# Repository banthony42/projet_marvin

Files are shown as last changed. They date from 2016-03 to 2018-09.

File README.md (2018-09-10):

# Projet Electronics 42
Le projet électronique consiste à fabriquer un prototype du projet de son choix : circuit et firmware. On n'utilise pas de raspberry pi ou d'arduino, on les fabrique ! Pour suivre ce projet vous aurez besoin de savoir lire l'anglais et d'avoir un niveau correct en C (opérations binaires notamment). Préparez-vous à suivre l'un des projets les plus durs du cursus et à sortir complètement de votre zone de confort. Vous serez en mode piscine au carré, et c'est voulu. Comptez une à deux journées par semaine minimum pendant 6 mois pour aller au bout du projet.

# projet_marvin
Le projet Marvin a pour ambition de construire une réplique animatronique du robot dépressif Marvin, personnage du Guide du Voyageur Galactique de Douglas Adams.

Etant donnée l'ampleur de la tâche, et afin de nous concentrer sur les aspects électroniques plutôt que sur la conception d'assemblages mécaniques, nous avons choisi de nous concentrer exclusivement sur la tête de cet humanoïde, à priori à une échelle de 1/3.

La tête de notre robot pourra se mouvoir selon deux axes (tangage et lacet) afin de suivre du “regard” son interlocuteur, comportera des éléments lumineux, des capteurs, ainsi que la capacité de jouer des extraits sonores via un haut-parleur.

Notre conception électronique assurera la régulation de la tension, l'asservissement des actionneurs ainsi que le traitement des signaux issus des capteurs.

En option, nous pourrons augmenter les capacités sensorielles de Marvin en adjoignant au PIC32 un ordinateur type Raspberry Pi ainsi que des capteurs avancés : deux micros pour la localisation d’une source de bruit, et une caméra pour un head tracking plus fin.

**Equipe du projet:
Lefr0g,
Aodren92,
banthony42,
Theo Beaumanoir**

### Aperçu des réalisations
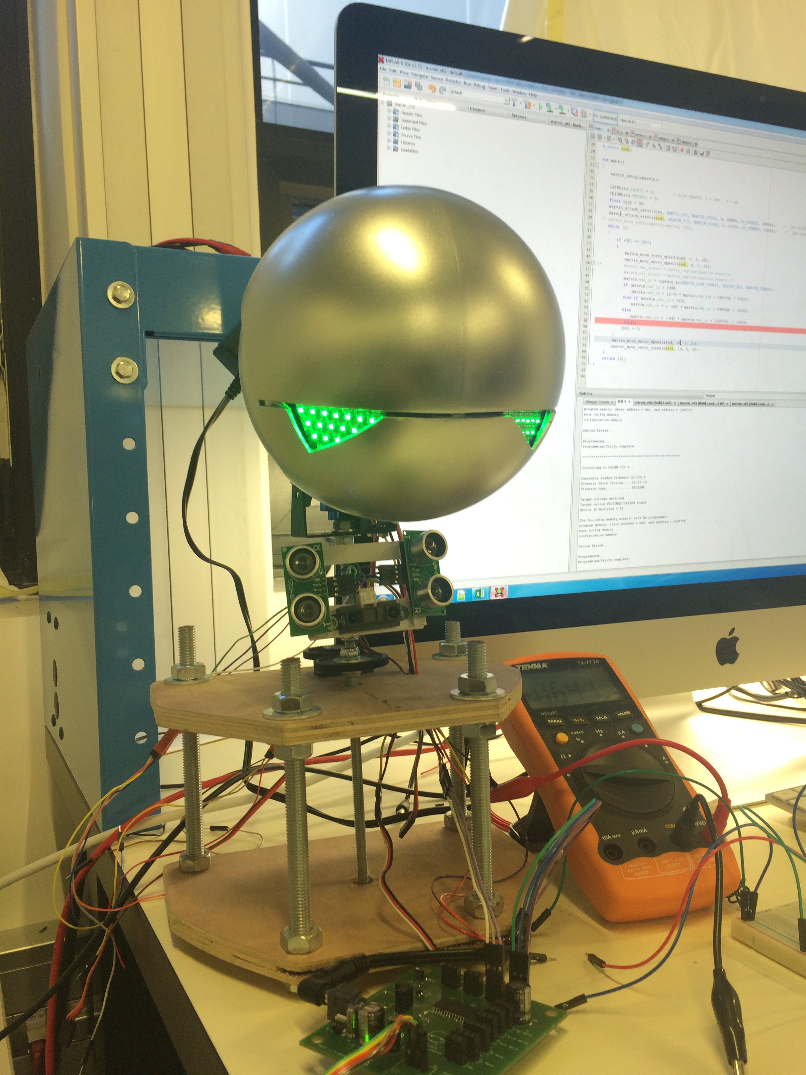
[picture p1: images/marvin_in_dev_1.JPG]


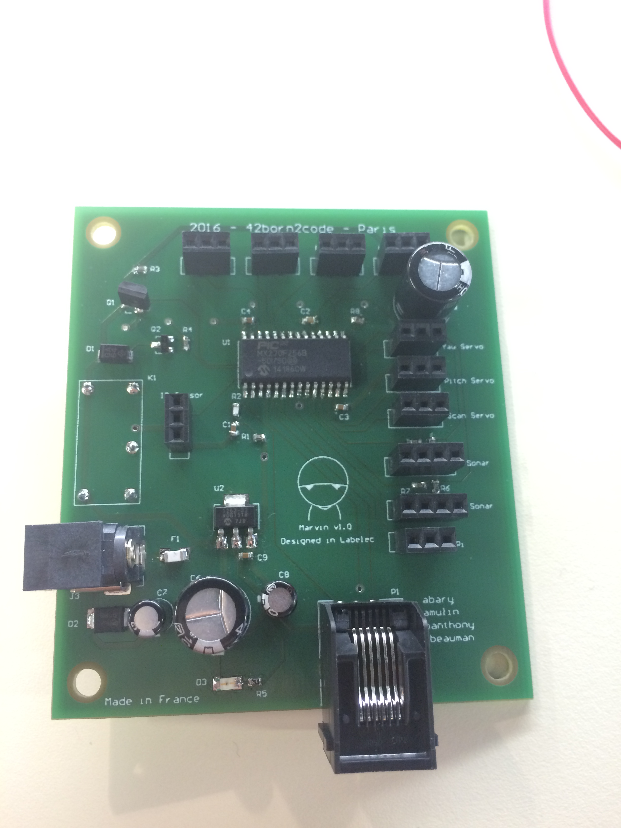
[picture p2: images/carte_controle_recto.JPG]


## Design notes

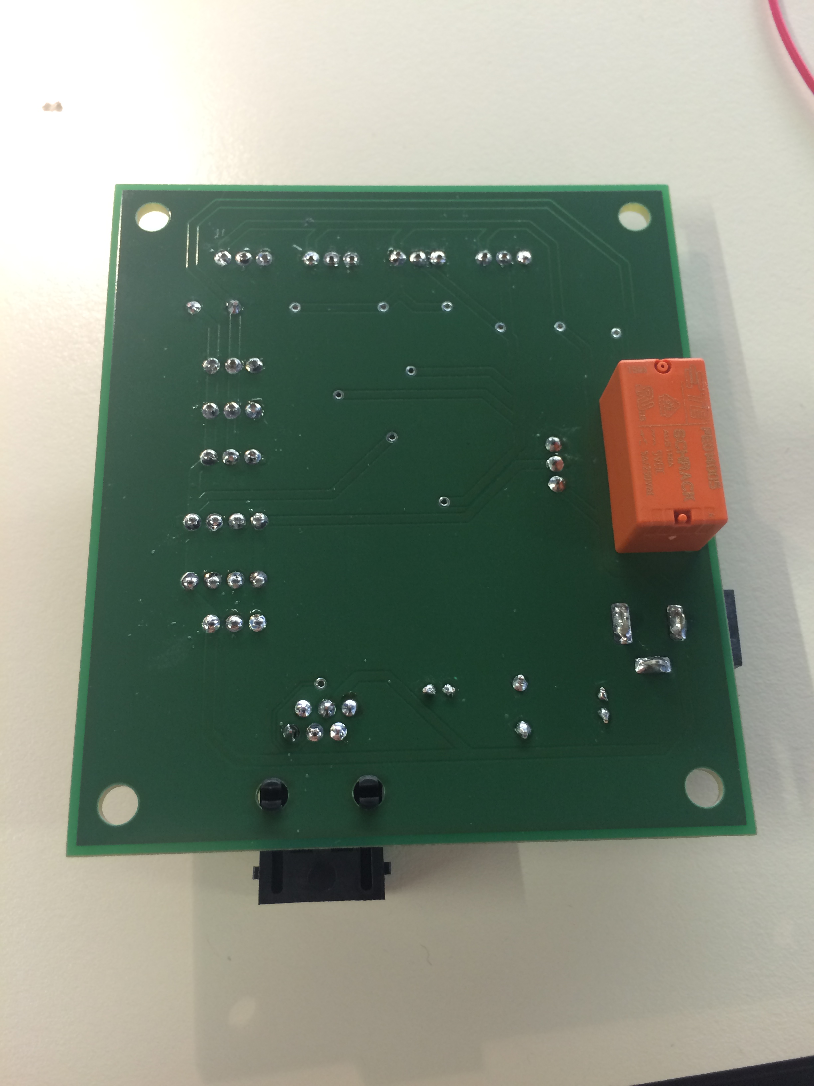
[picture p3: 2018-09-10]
images/carte_controle_verso.JPG

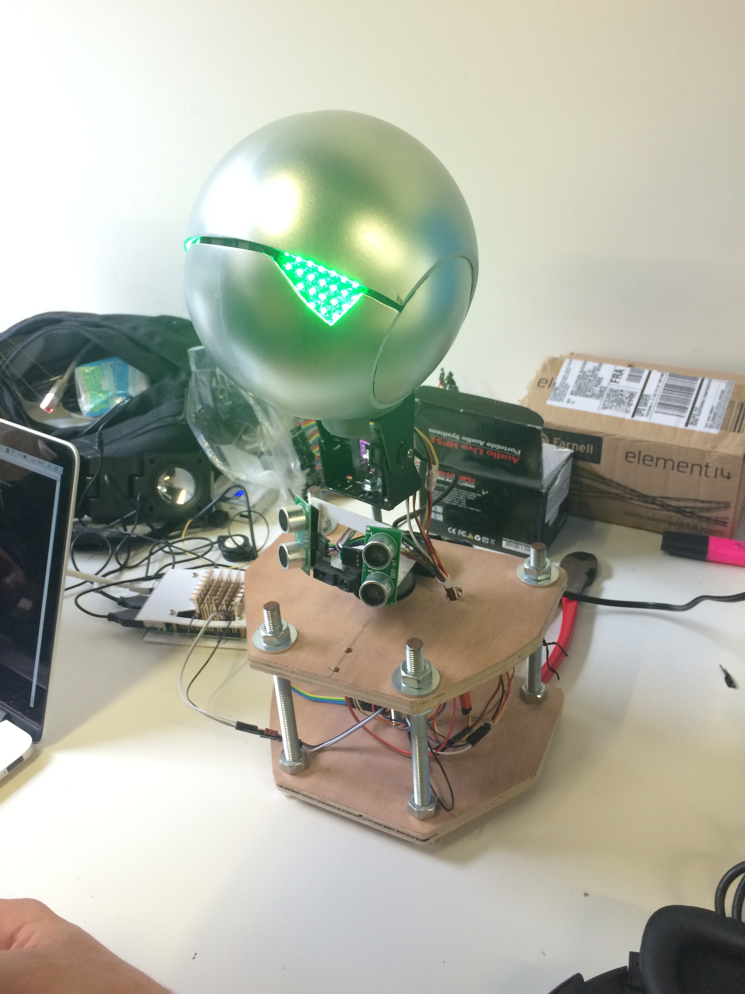
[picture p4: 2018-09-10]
images/marvin_in_dev_2.JPG

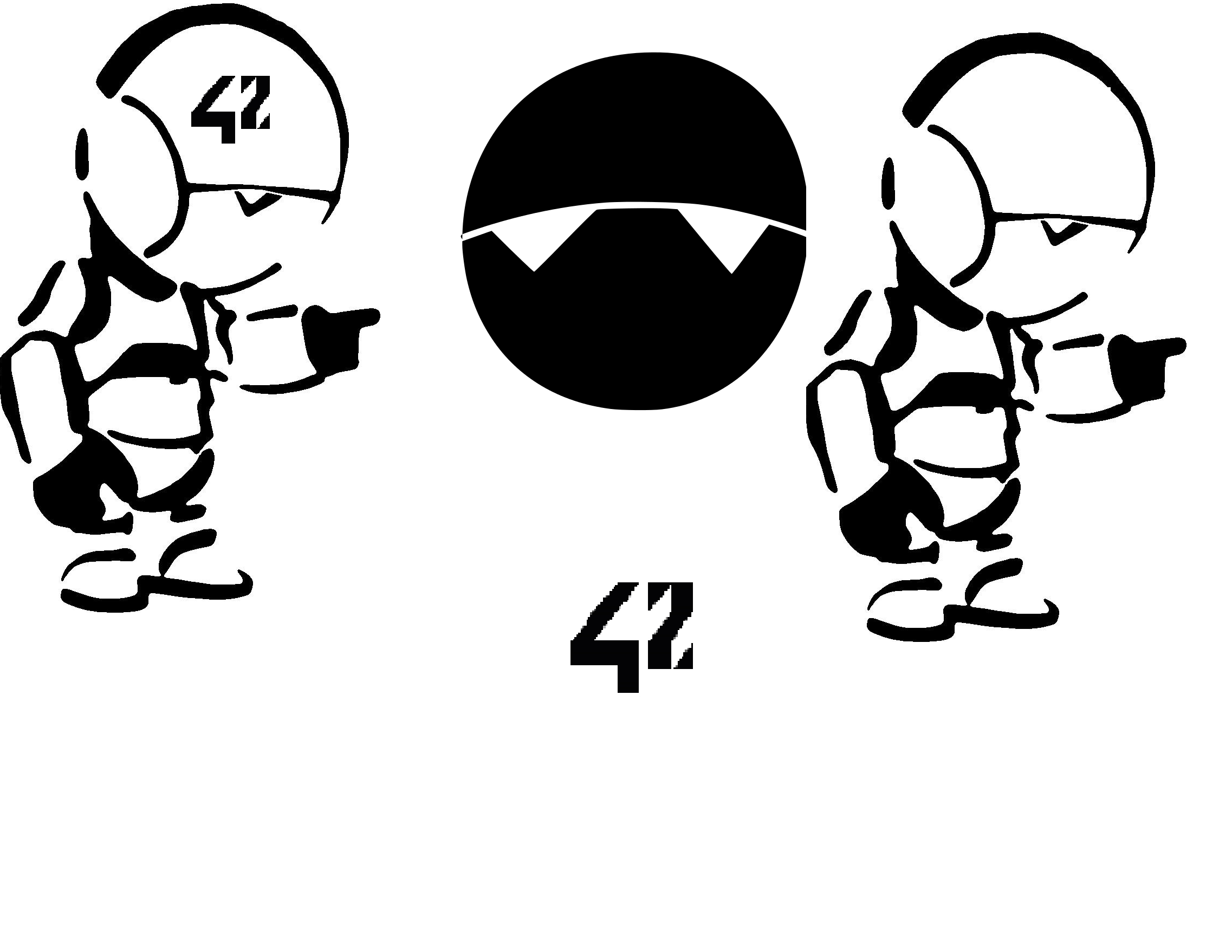
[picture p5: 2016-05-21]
POC/Altium/marvin_front.png

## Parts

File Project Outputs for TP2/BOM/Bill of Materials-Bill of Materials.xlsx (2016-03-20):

Comment | Description | DesignItemId | Quantity | Value | Fabricant | Footprint | Fournisseur | RefFabricant | RefFournisseur | Designator
100nF | Capacitor | Cap | 7 | 100pF |  | CAPC1608N |  |  |  | C1, C2, C3, C4, C5, C6, C15
20pF | Capacitor | Cap | 2 | 100pF |  | CAPC1608N |  |  |  | C7, C8
10uF | Capacitor | Cap | 4 | 100pF | [NoValue], TDK, TDK, TDK | CAPC2012N | [NoValue], Farnell, Farnell, Farnell | [NoValue], C2012X5R0J106M/1.25, C2012X5R0J106M/1.25, C2012X5R0J106M/1.25 | [NoValue], 2309029, 2309029, 2309029 | C9, C11, C12, C13
1uF | Capacitor | Cap | 2 | 100pF |  | CAPC1608N |  |  |  | C10, C14
GF1A | Default Diode | Diode | 2 |  | VISHAY | SMA/DO-214AC_21 | Farnell | GF1A-E3/67A | 9549560 | D2, D3
Green LED | Typical RED, GREEN, YELLOW, AMBER GaAs LED | LED2 | 5 |  | KINGBRIGHT | LED 0805 | Farnell | KPT-2012SGC | 2099239 | D4, LED3_LED0, LED3_LED1, LED3_LED2, LED3_LED3
600r | Inductor | Inductor | 1 | 600r | Wurth | INDC1608AN | Farnell | 742792651 | 1635706 | FB1
Program / Debug |  | Program / Debug | 1 |  | Molex | RJ12_90 | Farnell | 53398-0671 | 1125368 | J1
12V Main | Header, 2-Pin | Header 2 | 1 |  | PHOENIX CONTACT | PHOENIX_1985195 | Farnell | PTSA1.5/2-3.5-Z | 1792679 | P1
12V Battery | Header, 2-Pin | Header 2 | 1 |  | PHOENIX CONTACT | PHOENIX_1985195 | Farnell | PTSA1.5/2-3.5-Z | 1792769 | P2
10k | Potentiometer | RPot | 1 | 10K | Bourns | PDB181-K415K-102A2 | Farnell | 'PDB181-K415K-102A2 | '1823540 | R1
330r | Resistor | Res1 | 4 | 1K |  | RESC1608N |  |  |  | R2_LED0, R2_LED1, R2_LED2, R2_LED3
4.7k | Resistor | Res1 | 1 | 1K |  | RESC1608N |  |  |  | R3
470r | Resistor | Res1 | 1 | 1K |  | RESC1608N |  |  |  | R4
PIC32MX764F128H-I/PT |  | PIC32MX764F128H-I/PT | 1 |  | Microchip | QFP50P1200X1200X120-64 | Farnell | PIC32MX764F128H-I/PT | 1971889 | U1
AP1117 |  | AP1117 | 1 |  | DIODES INC | TD03B_N | Farnell | AP1117D33G-13 | 1825285 | U2
8MHz | Crystal Oscillator | XTAL | 1 |  | FOX ELECTRONICS | HC49/4H SMX CRYSTAL | Farnell | FOXSDLF/080-20 | 2063972 | Y1

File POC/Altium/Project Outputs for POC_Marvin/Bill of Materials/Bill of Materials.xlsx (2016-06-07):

Comment | Description | Footprint | LogicalDesignator | Quantity | fabricant | reffabricant | fournisseur | reffournisseur
470uF | Capacitor | CONDO_D_10mm | C5, C6 | 2 | Panasonic | ECA-1EHG471, [NoValue] | Farnell | 9692843
10uF | Capacitor | CONDO_D_5MM | C7, C8 | 2 | Panasonic | ECA-1JHG100 | Farnell | 1848557
GF1A | Default Diode | SMA/DO-214AC_21 | D1 | 1 | VISHAY | GF1A-E3/67A | Farnell | 9549560
Zener 1SMB5918BT3G | Zener Diode | DIODE ZENER | D2 | 1 | ON SEMICONDUCTORS | 1SMB5918BT3G | Farnell | 1431161
150120VS75000 | Green LED | 3216 / 1206 | D3 | 31 | WURTH ELEKTRONIK | 150120VS75000 | Farnell | 2322088
1206SFF500F/32-2 | Fuse | 3216 / 1206 | F1 | 5 | TE CONNECTIVITY / RAYCHEM | 1206SFF500F/32-2 | Farnell | 1843811
IR_Connector | Female Embase 3 contacts | IR SENSOR CONNECTOR | J1 | 1 | TE CONNECTIVITY / AMP | 5-534237-1 | Farnell | 1845931
Potard_Connector | Female Embase 3 contacts | POTARD CONNECTOR | J2 | 2 | TE CONNECTIVITY / AMP | 5-534237-1 | Farnell | 1845931
PWR2.5 RAPC712BK | Jack Connector | RAPC712BK | J3 | 1 | SWITCHCRAFT | RAPC712BK | Farnell | 1617204
RPi_Connector | Female Embase 3 contacts | RPI CONNECTOR | J4 | 1 | TE CONNECTIVITY / AMP | 5-534237-1 | Farnell | 1845931
Servo_Connector | Female Embase 3 contacts | SERVO CONNECTOR | J5 | 3 | TE CONNECTIVITY / AMP | 5-534237-1 | Farnell | 1845931
Sonar_Connector | Female Embase 4 contacts | SONAR CONNECTOR | J6 | 2 | TE CONNECTIVITY / AMP | 5-534237-2 | Farnell | 1845959
Leds_Connector | Female Embase 3 contacts | LEDS CONNECTOR | J7 | 2 | TE CONNECTIVITY / AMP | 5-534237-1 | Farnell | 1845931
Relay PE014005 | Relay | PE014005 | K1 | 1 | TE CONNECTIVITY / SCHRACK | PE014005 | Farnell | 1175088
RJ11 Debug | RJ11 Connector | RJ11 | P1 | 1 | MOLEX | 95009-7661 | Farnell | 2076092
MOSFET-N 2N7002K | N-Channel MOSFET | SOT23 | Q2 | 1 | FAIRCHILD SEMICONDUCTOR | 2N7002K | Farnell | 2453382
PIC32MX270F256B | PIC32MX270F256B | SOIC28 | U1 | 1 | Microchip | PIC32MX270F256B-50I/SO | Farnell | 2419680
Regul LD1117S33TR | Voltage Regulator | SOT-223 | U2 | 1 | ST MICRO | LD1117S33TR | Farnell | 1202826

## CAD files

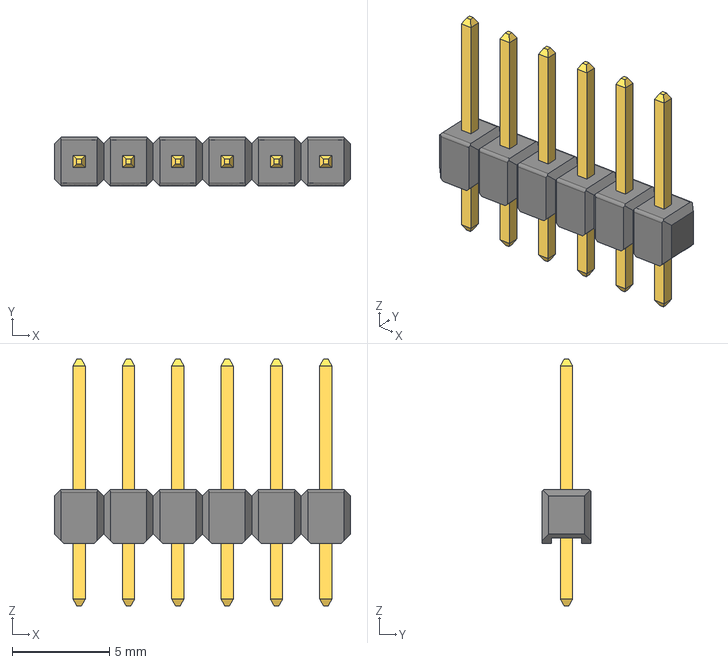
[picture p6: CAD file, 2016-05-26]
POC/Altium/Pin Header 1x6 TH Pitch 2.54mm.stp
15.2 x 2.54 x 12.7 mm

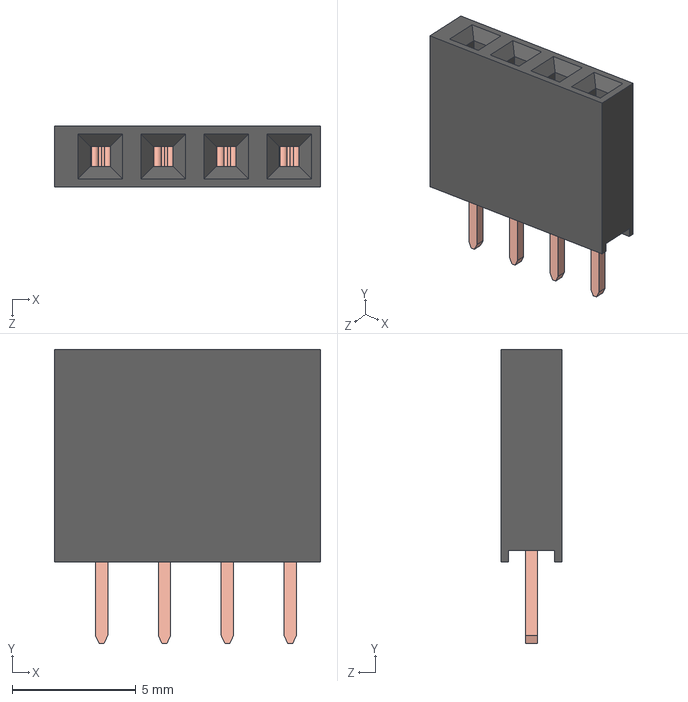
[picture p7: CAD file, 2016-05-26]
POC/Altium/SIMON_4pinheader-female-STEP.STEP
10.8 x 11.9 x 2.48 mm

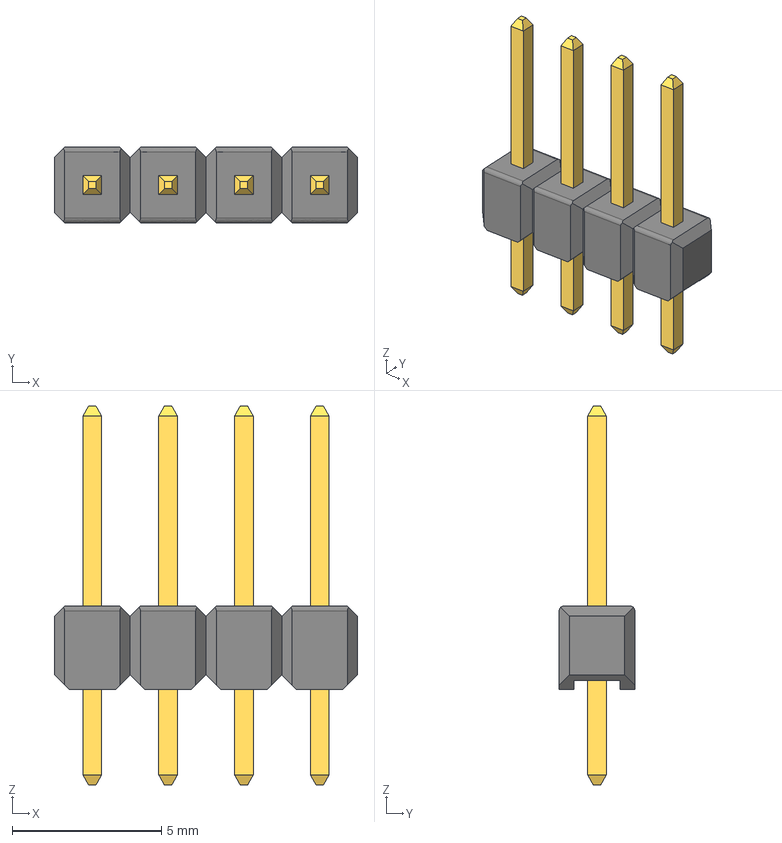
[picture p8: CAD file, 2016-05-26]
POC/Altium/Pin Header 1x4 TH Pitch 2.54mm.stp
10.2 x 2.54 x 12.7 mm

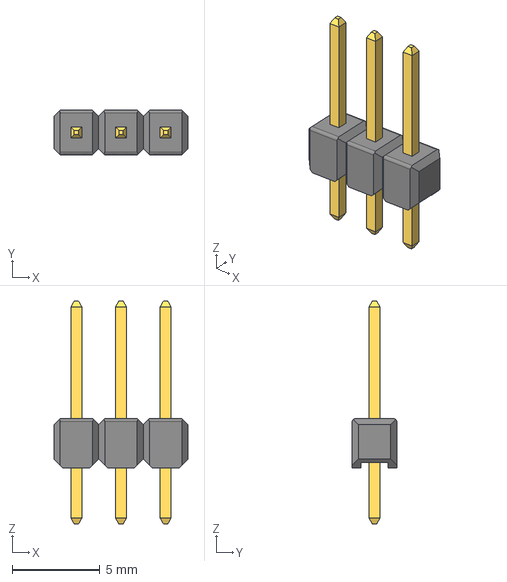
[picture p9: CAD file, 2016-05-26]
POC/Altium/Pin Header 1x3 TH Pitch 2.54mm.stp
7.62 x 2.54 x 12.7 mm

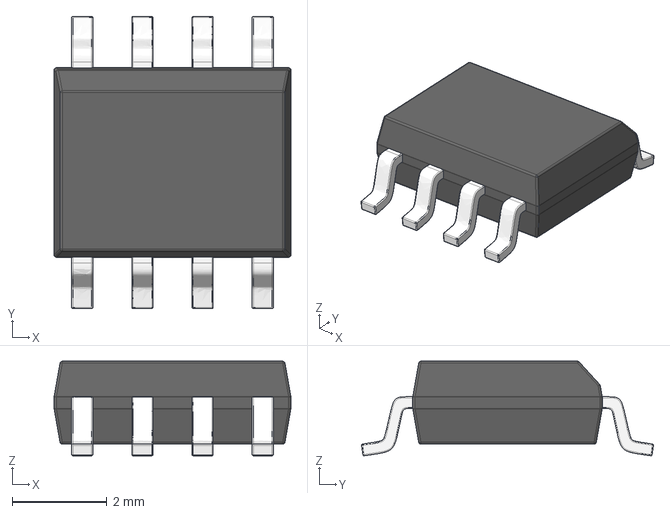
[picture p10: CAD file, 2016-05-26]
POC/Altium/SOIC08 narrow.stp
5.00 x 6.16 x 2.00 mm

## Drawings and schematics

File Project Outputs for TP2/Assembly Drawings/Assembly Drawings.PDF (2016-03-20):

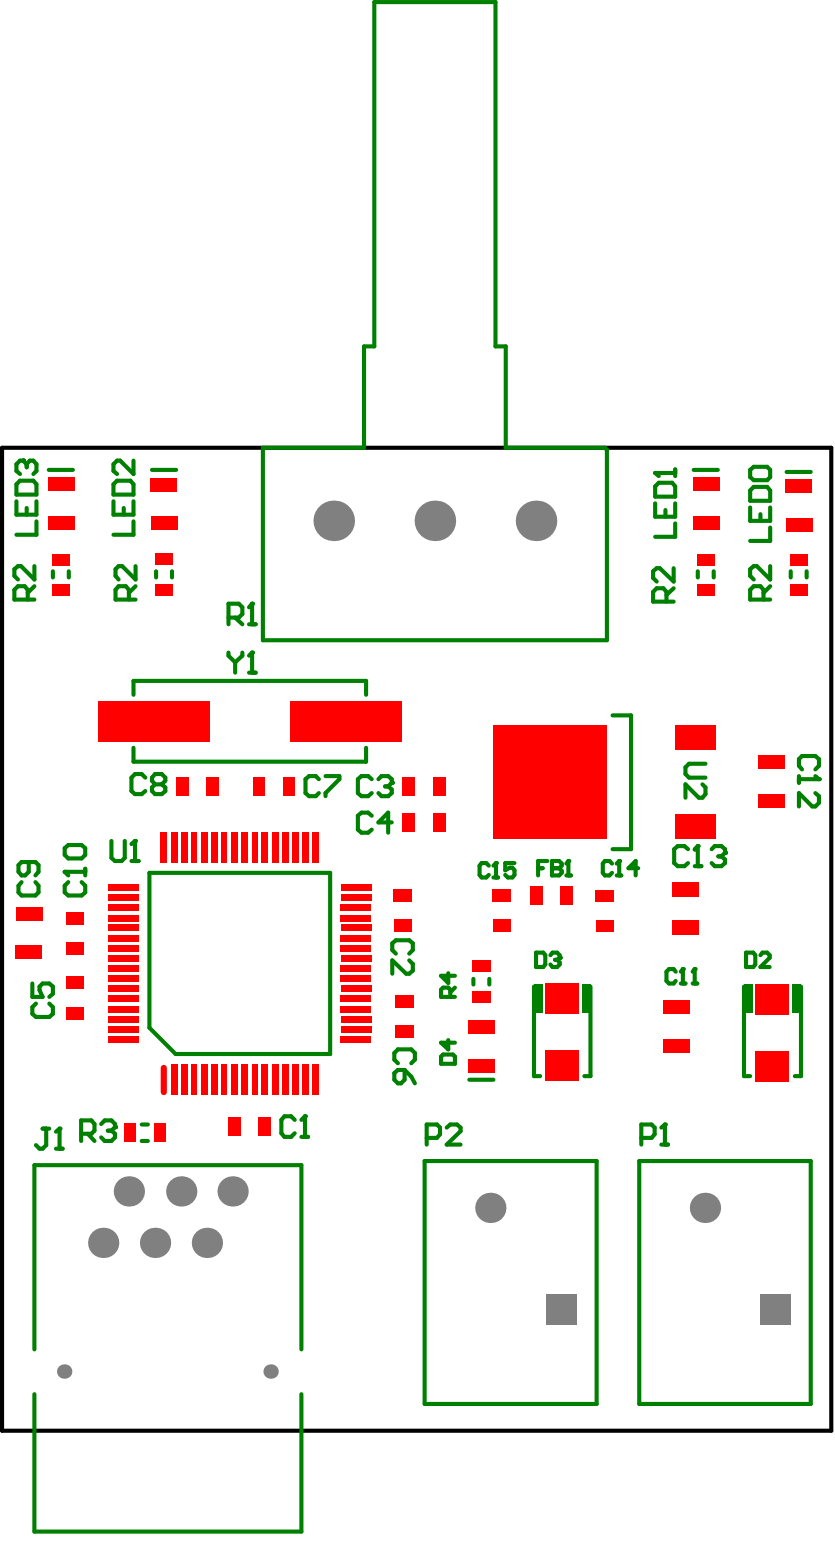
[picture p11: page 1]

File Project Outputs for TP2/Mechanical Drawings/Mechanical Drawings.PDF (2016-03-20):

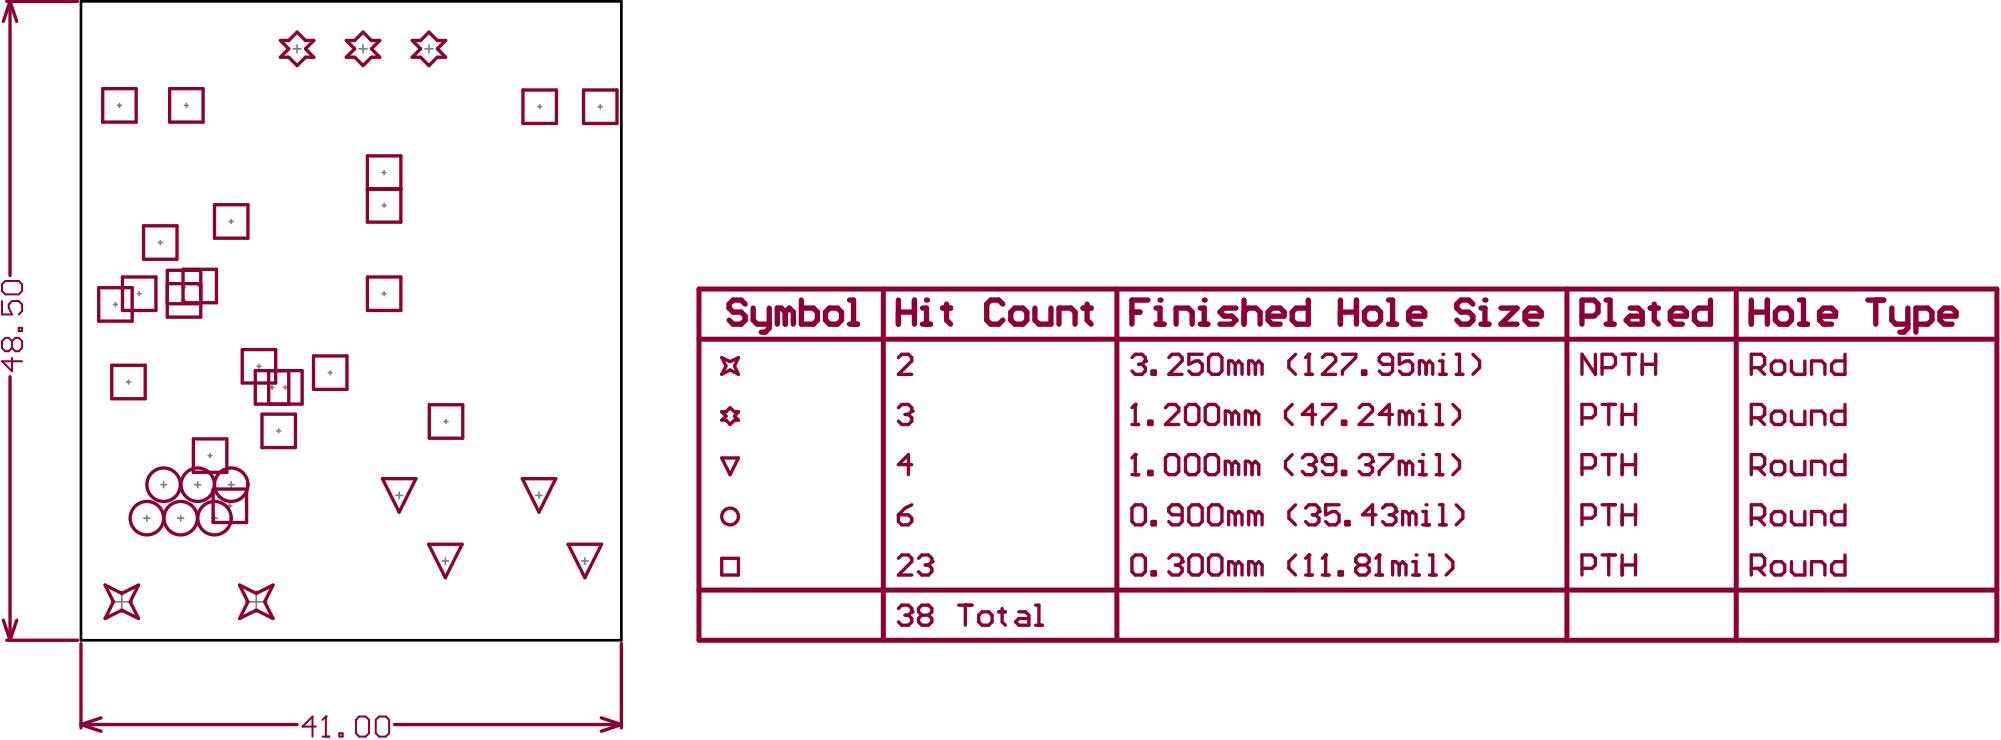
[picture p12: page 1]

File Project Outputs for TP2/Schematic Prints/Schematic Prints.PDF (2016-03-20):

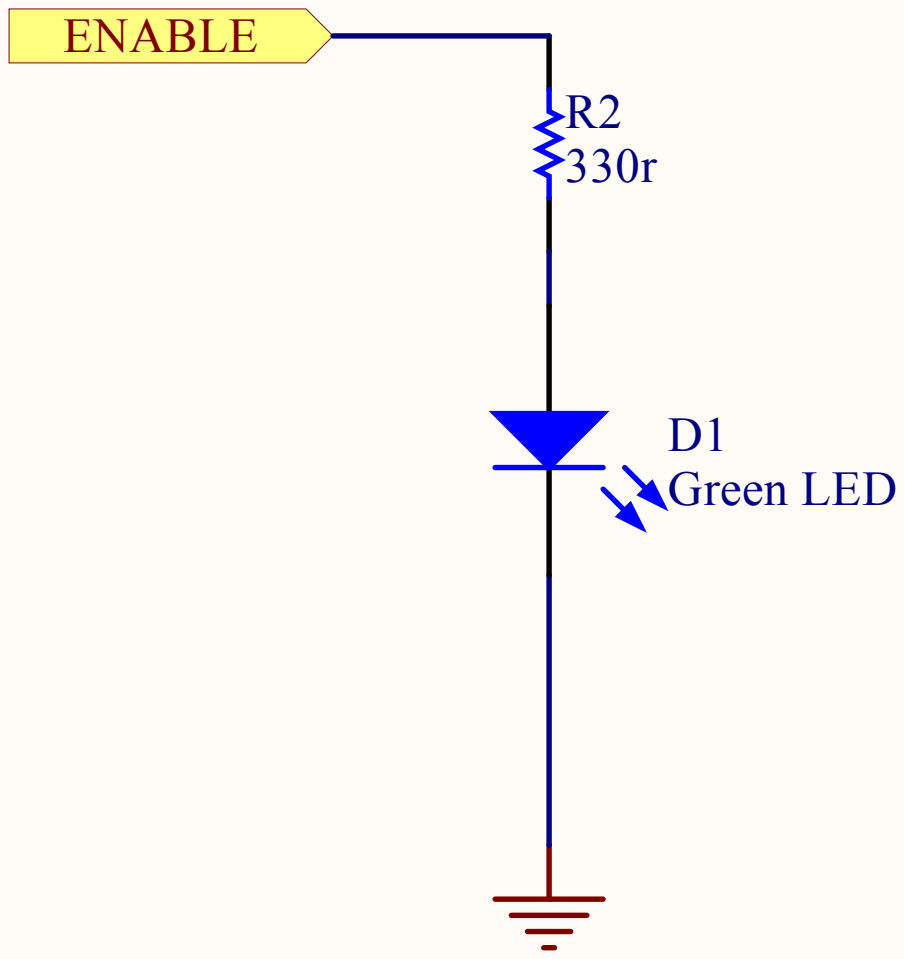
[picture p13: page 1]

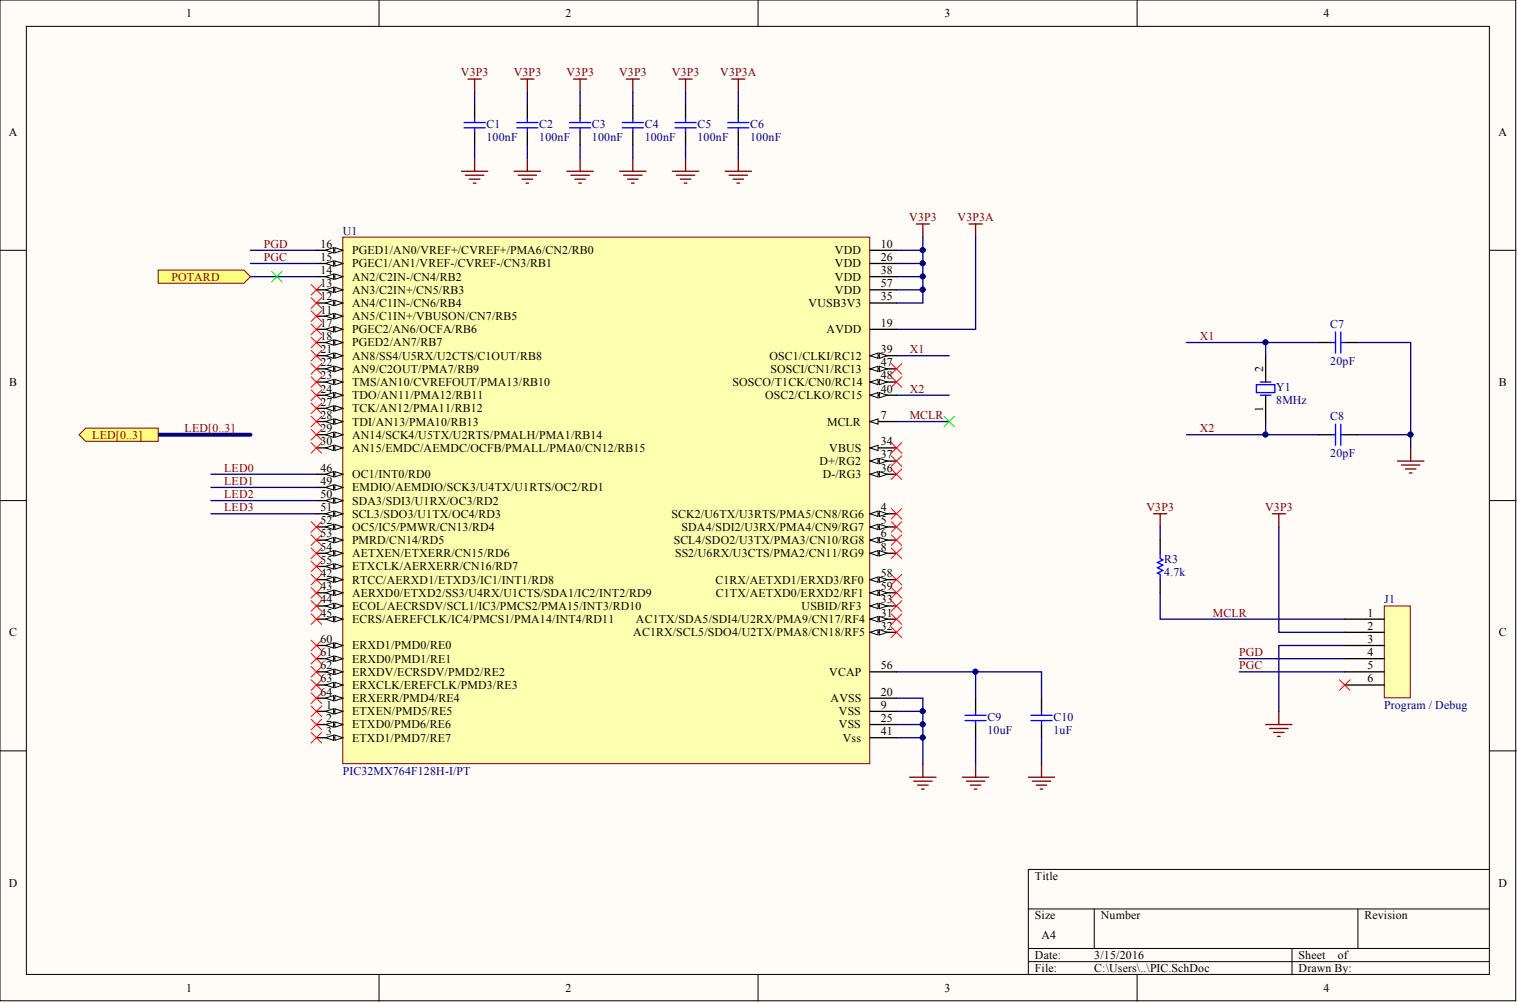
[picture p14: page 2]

MCLR

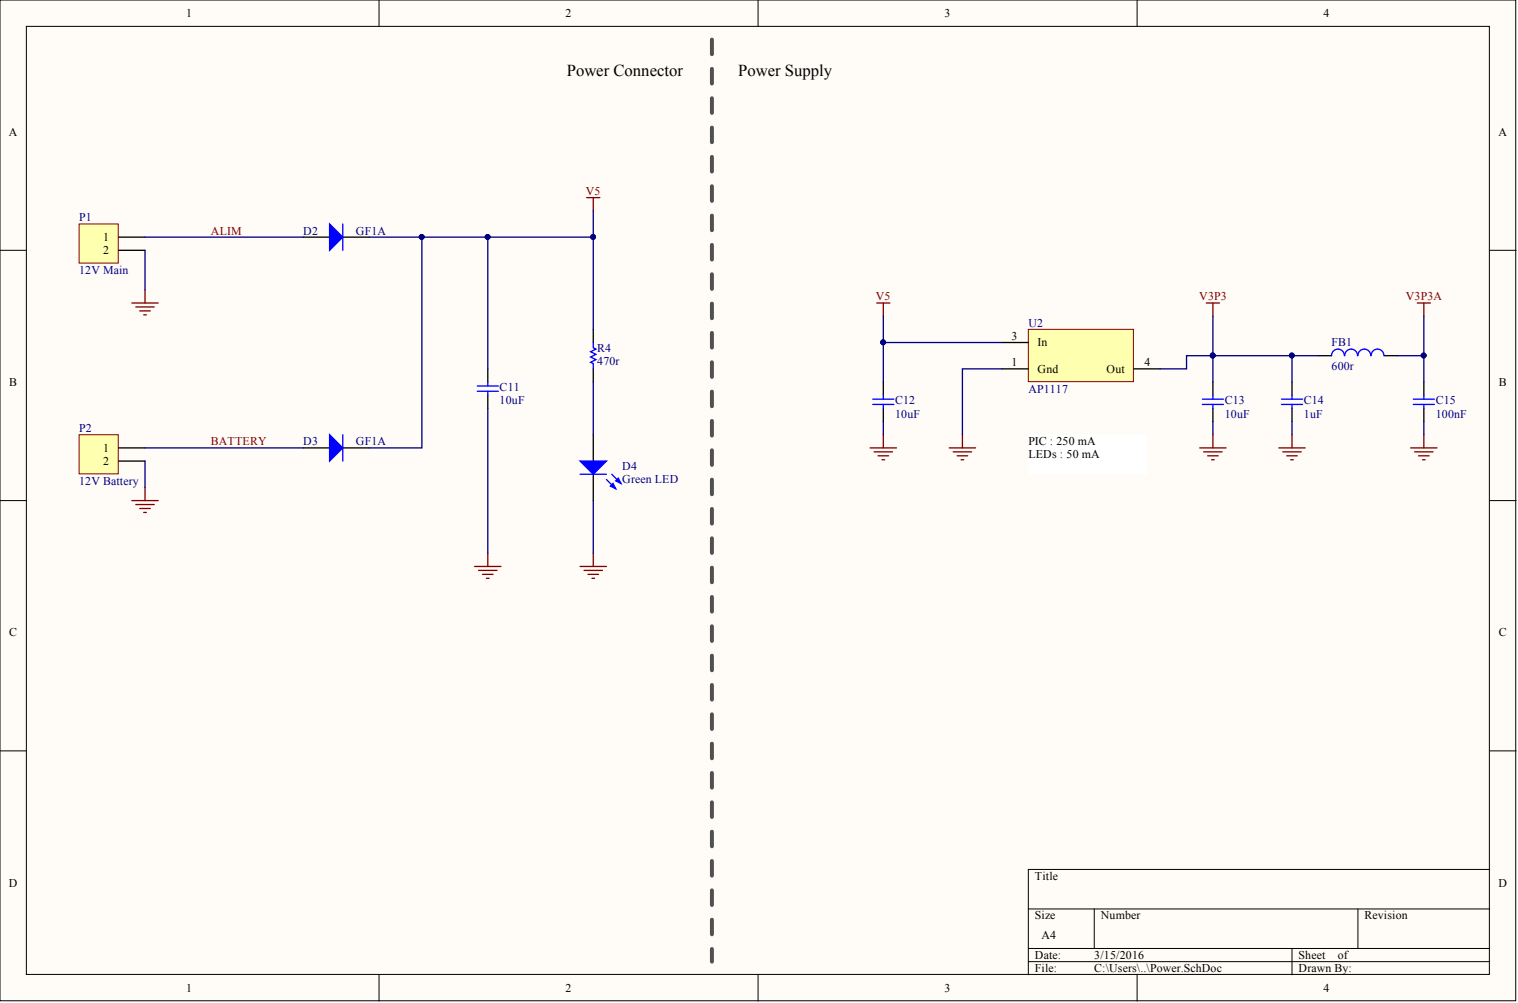
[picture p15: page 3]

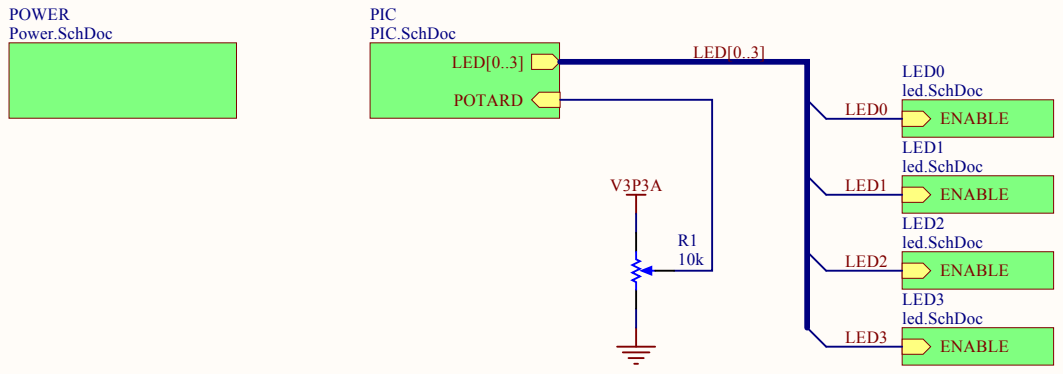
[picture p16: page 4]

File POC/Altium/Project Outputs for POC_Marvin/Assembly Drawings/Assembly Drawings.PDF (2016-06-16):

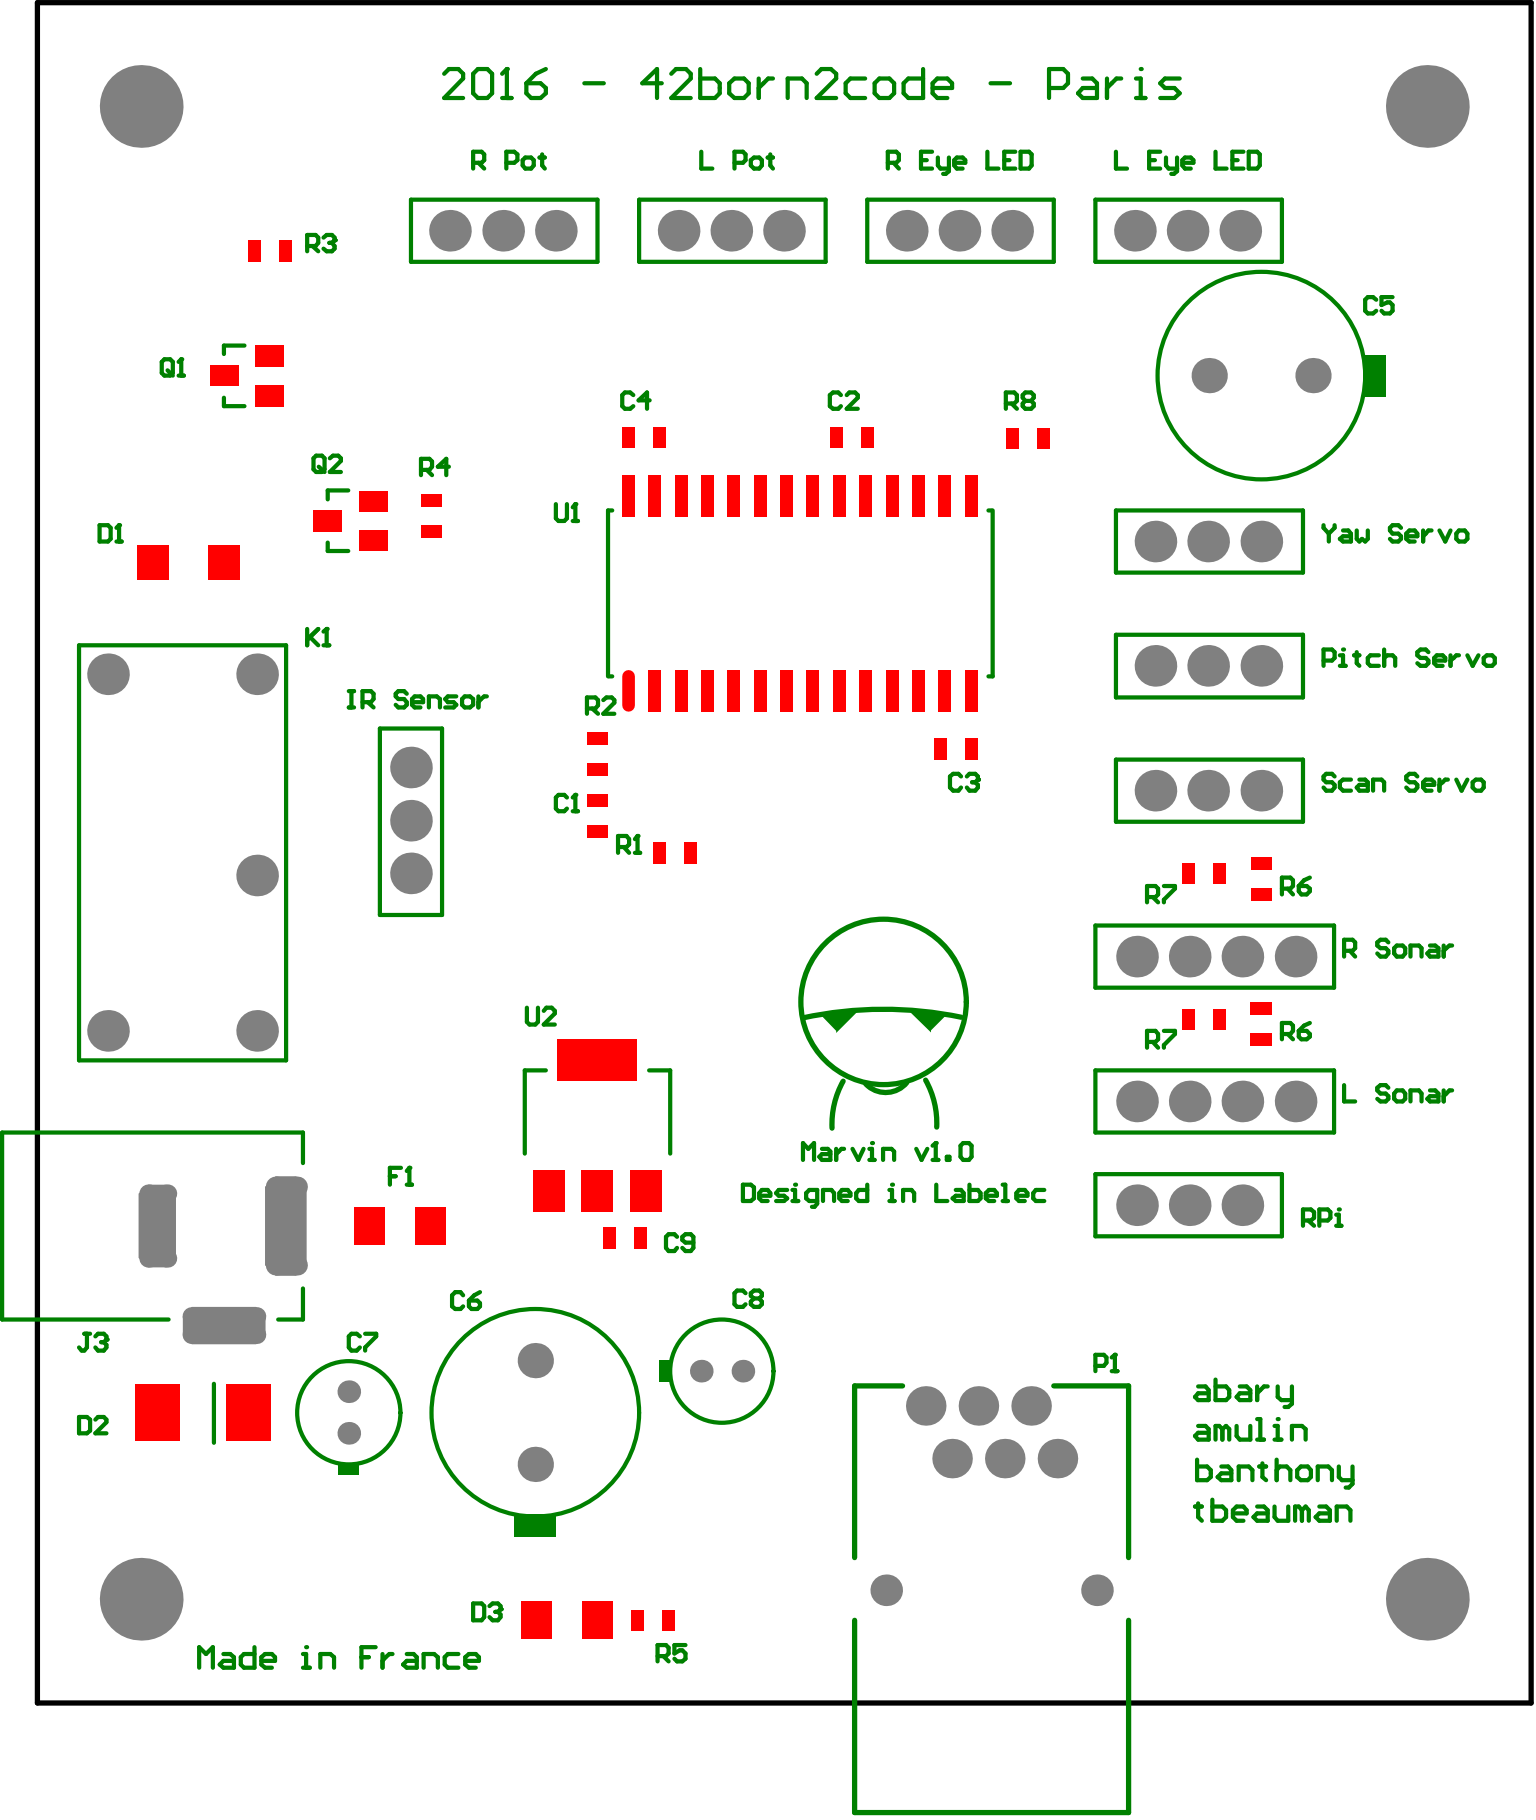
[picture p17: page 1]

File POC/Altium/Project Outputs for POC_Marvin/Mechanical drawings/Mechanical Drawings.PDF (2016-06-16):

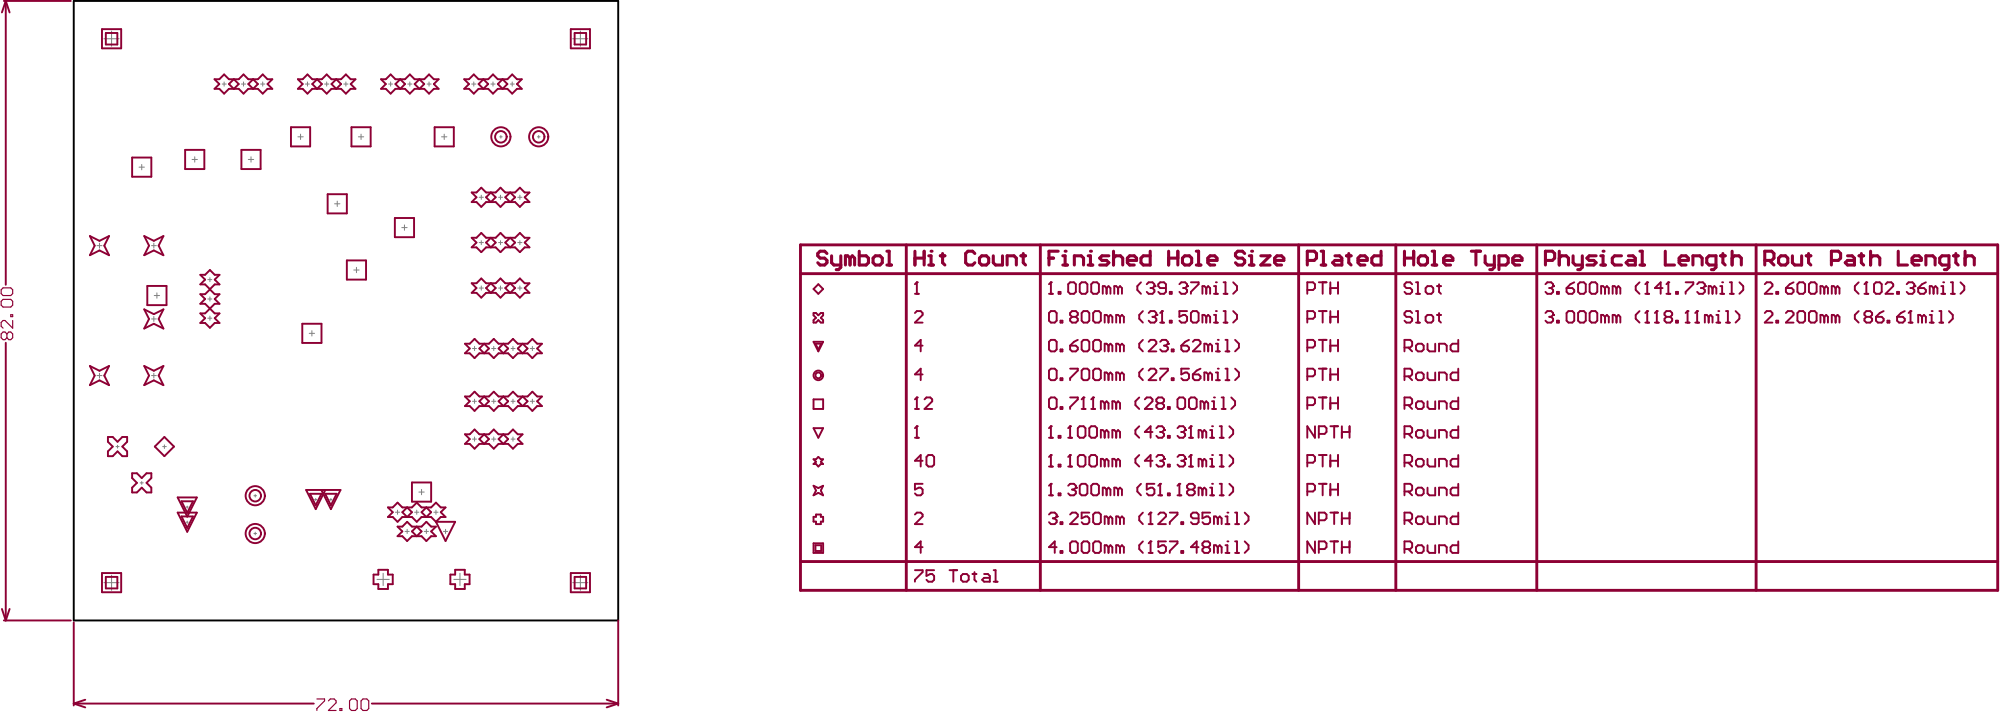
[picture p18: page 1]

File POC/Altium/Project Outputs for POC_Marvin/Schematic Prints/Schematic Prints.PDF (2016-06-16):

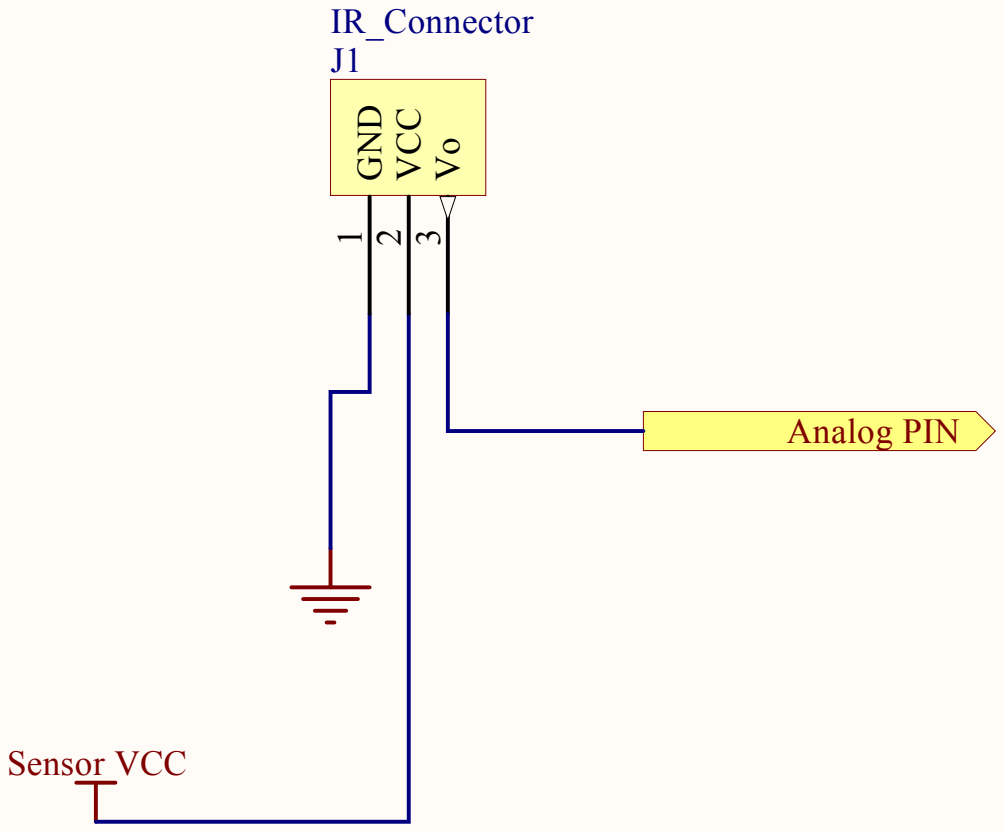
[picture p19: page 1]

Title | Altium Limited L3, 12a Rodborough Rd Frenchs Forest NSW Australia 2086

Size: A4 | Number: | Revision:
Date: 6/16/2016 Time: 5:52:42 PM | | Sheet of

C:\Users\bocal\Documents\projet_marvin\POC\Altium\IrSensor.SchDoc
File:

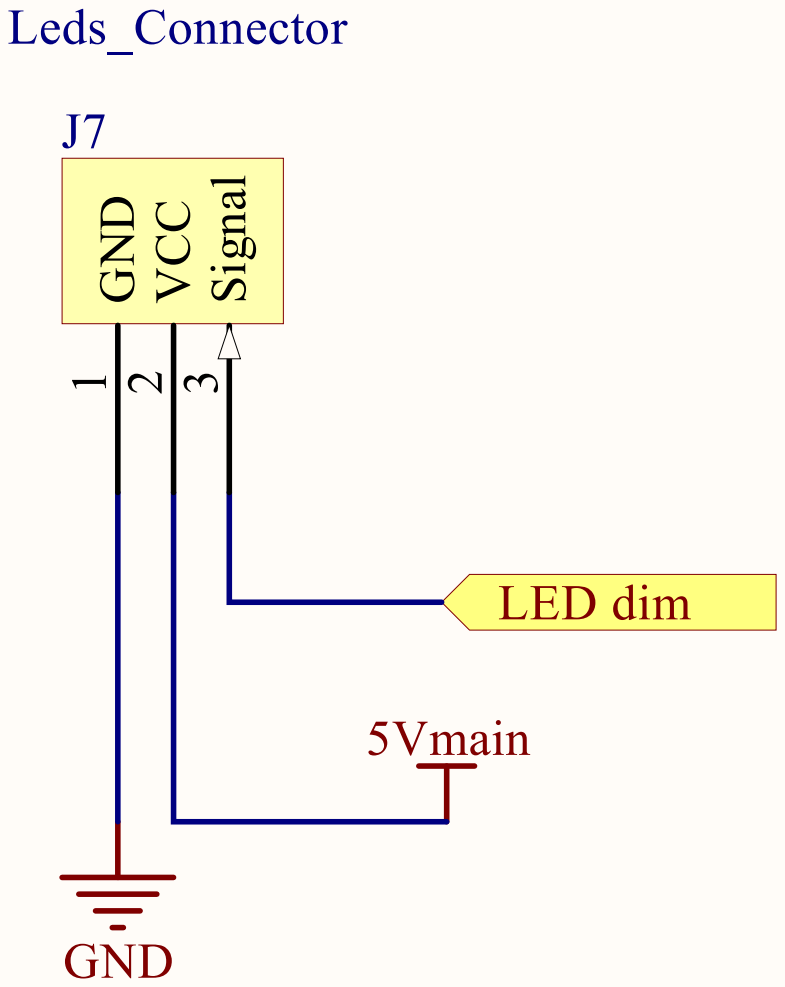
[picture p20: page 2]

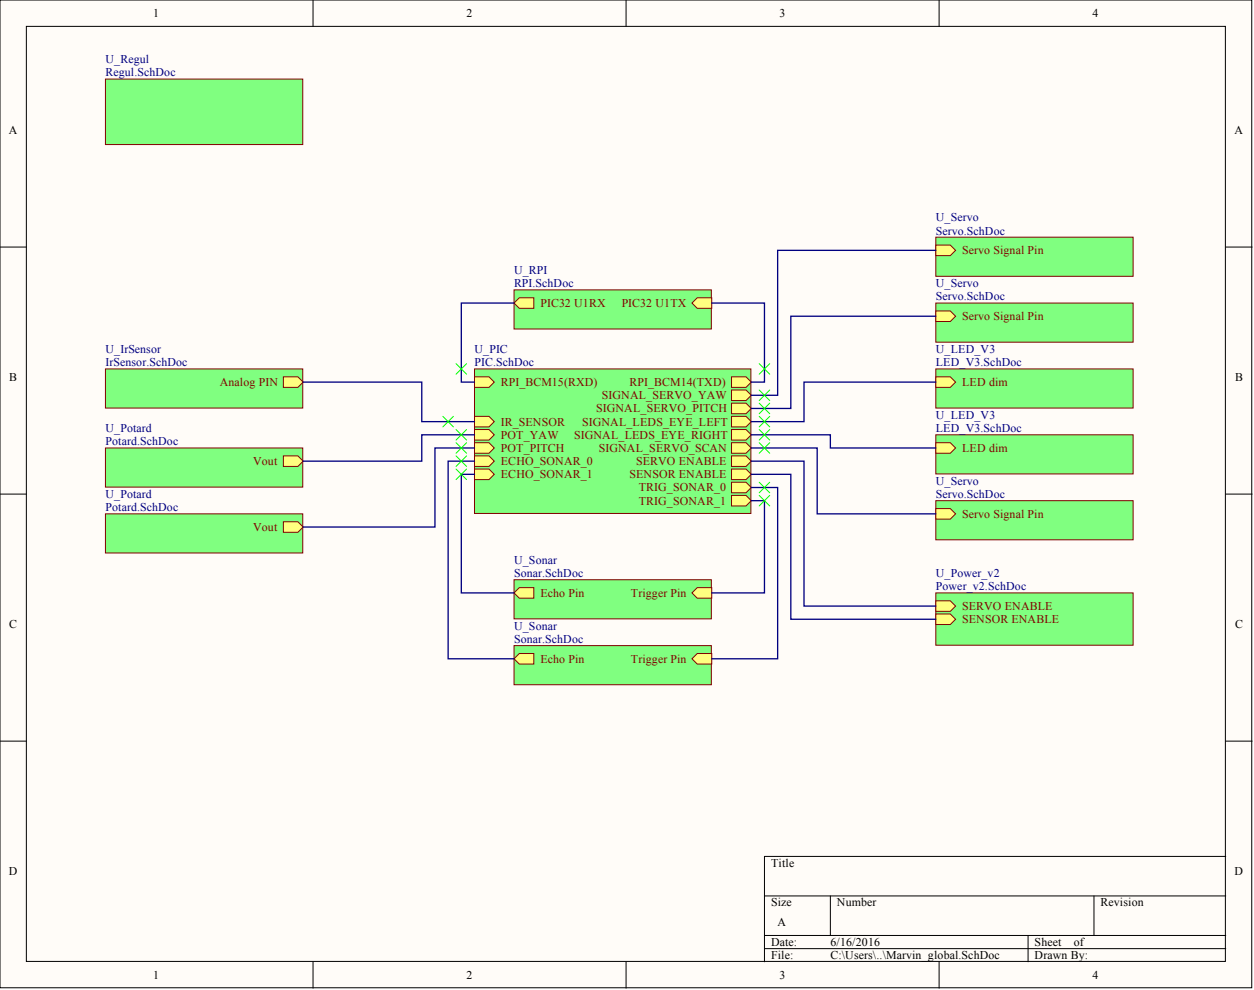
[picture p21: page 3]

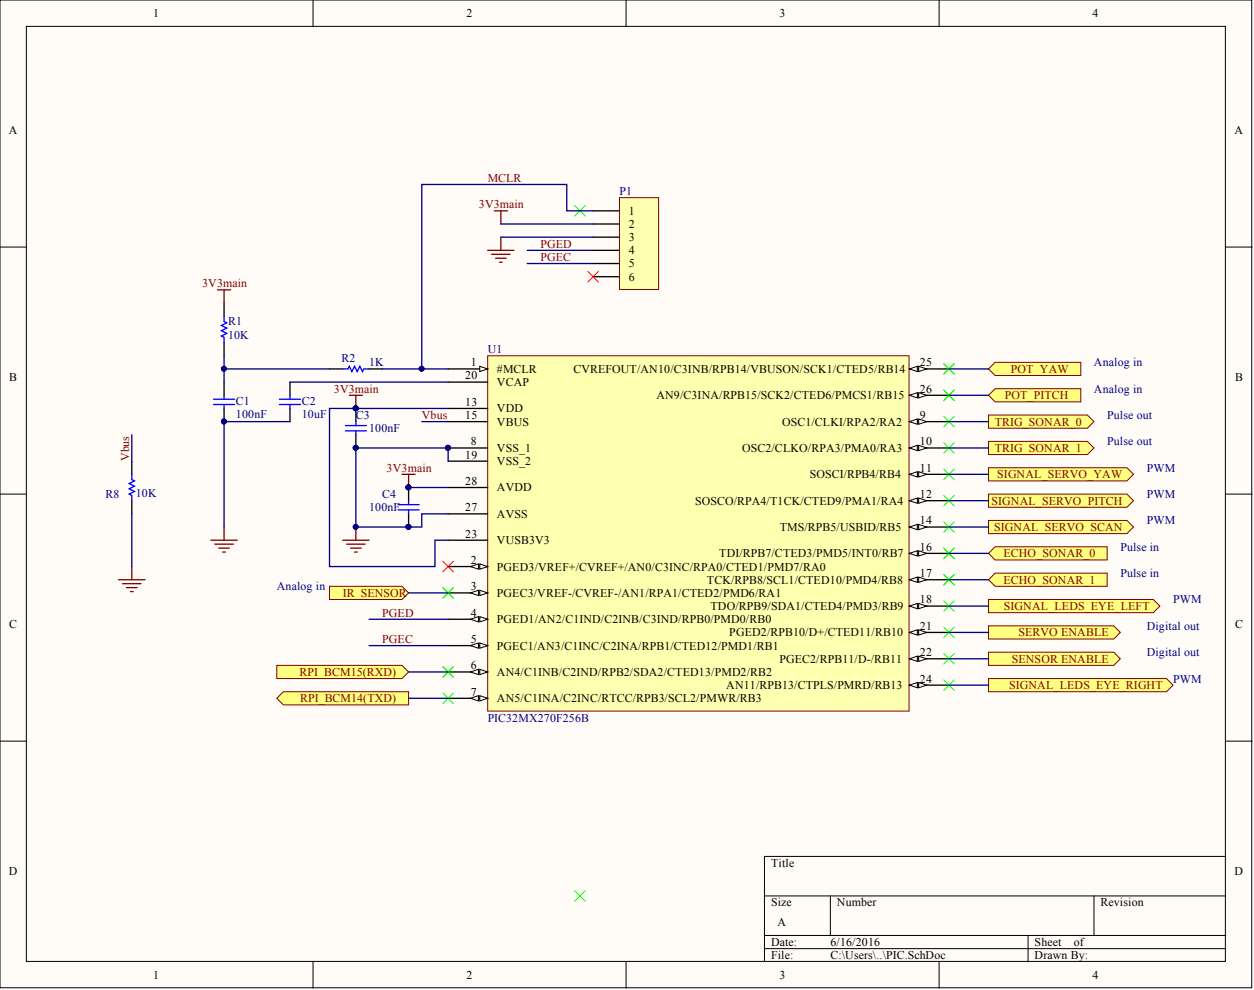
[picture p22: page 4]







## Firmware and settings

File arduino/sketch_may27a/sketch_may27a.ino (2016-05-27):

#include <Servo.h>


/*
 * Prototype projet marvin
 */

#define BUTTON 5
#define LED 13
#define E_S1 8
#define E_S2 6
#define T_S1 9
#define T_S2 7
#define SERVO 11

Servo servo1; // objet servo
void setup() {
  //Init du Button
   pinMode(BUTTON, INPUT);
   // Init de la Led a l'etat eteind
   pinMode(LED, OUTPUT);
   digitalWrite(LED, HIGH);
   //Init du baud rate du monitor
   Serial.begin(9600);
   //Init des Sonars
   pinMode(T_S1, OUTPUT); 
   pinMode(T_S2, OUTPUT);
   digitalWrite(T_S1, LOW);
   digitalWrite(T_S2, LOW);
   pinMode(E_S1, INPUT);
   pinMode(E_S2, INPUT);   
   //I11nit su servo
  // pinMode(SERVO, OUTPUT);
  servo1.attach(11);
}

/*
 * fonction qui tri par insertion
 * Param1: tableau qui contiendras les valeurs triees
 * Param2: taille du tableau
 * Param3 valeur a inserer
 */
 
void  tri_insertion(int *tab, int size, int valeur)
{
  int *pos;
  
  while (size && *tab < valeur)
  {
    ++tab;
    --size;
  }
  pos = tab;
  if (size)
  {
    while (size)
    {
      ++tab;
      --size;
    }
    while (tab > pos)
    {
      *tab = *(tab - 1);
      tab--;
    }
  }
  *pos = valeur;
}

/*
 * Retourne la medianne d'une serie de valeur
 * Param1: tableau de valeurs, le tableau doit etre trier par ordre croissant
 * Param2 : Taille du taleau
 * Return : La medianne 
 */
int   calcul_median(int *tab, int size)
{
  int index;
  int nbrzero = 0;

  // Pour pallier au bug du Sonar on va ignorer les zeros;

  while (*(tab + nbrzero) == 0 && nbrzero < size)
      ++nbrzero;
  index = (size - nbrzero +  1) / 2 ;
  if (index  > size)
      return (0);
  if ((size + 1 ) % 2 == 0)
  {
    
    return (*(tab + index -1 + nbrzero)); // -1 car on commenc a comtper a partir de zero;
  }
   else
   return ( (*(tab + index - 1 +nbrzero) + *(tab + index +nbrzero)) / 2) ;
}

#define SIZE_SONAR 11
int   capture_sonar(int echo, int trigger)
{
  int tab[SIZE_SONAR] = {0};
  int size = 0;

  
  while (size < SIZE_SONAR)
  {
    digitalWrite(trigger, HIGH);
    delayMicroseconds(10);
    digitalWrite(trigger, LOW);
    tri_insertion(tab, size, pulseIn(echo, HIGH) / 58);
    ++size;
  }
  print_tab(tab, SIZE_SONAR); // pour les tests
  return (calcul_median(tab, SIZE_SONAR));
  
}

/*
 * Imprime un tableau sur le monitor pour le debug
 * Param1 : tableau a afficher
 * Param2 : taille du tableau
 */
 
void  print_tab(int *tab, int size)
{
  while (size)
  {
    Serial.println(*tab);
    size--;
    tab++;
  }
  Serial.println("--------------------");
}

int tab[12] = {0};
int test[12] = { 3, -4, 2 , 1 ,56, 76, 87, 98, 54, 34, 5, 104};
int size = 0;

void loop() {
// test du button
  if (digitalRead(BUTTON) == HIGH)
  {
    int s1, s2 = 0;
    s1 = capture_sonar(E_S1, T_S1);
    s2 = capture_sonar(E_S2, T_S2);
    if (s1 > s2)
    {
       Serial.println("a gauche");
      servo1.write(0);
      // tourner le servo a gauche
    }else
    {
      Serial.println("a droite");
      servo1.write(180);
      //tourner le servo a droite
    }
    //test du sonar2
     delay(500);
  }
}

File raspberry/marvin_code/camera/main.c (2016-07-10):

#include "client.h"
#include <stdio.h>
#include <errno.h>
#include <string.h>
#include <unistd.h>
#include <stdlib.h>

int	main(int argc , char ** argv)
{
	if(argc < 2)
	{
		printf("Usage : %s [address] [pseudo]\n", argv[0]);
		return 1;
	}

	char buffer[BUF_SIZE_SOCKET];

	fd_set rdfs;
	//SOCKET define sur intd
	SOCKET sock = init_connection(argv[1]);

	/* send our name*/
	write_server(sock, argv[2]);


	while (1)
	{
		FD_ZERO(&rdfs); // Vide l'ensemble
		/*add STDION_FILENO */ //descripteur 0
		FD_SET(STDIN_FILENO, &rdfs);
		/* add socket*/
		FD_SET(sock, &rdfs);

		if (select(sock + 1, &rdfs, NULL, NULL, NULL) == -1)
		{
			perror("error select");
			exit(errno);
		}
		if (FD_ISSET(STDIN_FILENO, &rdfs))
		{
			fgets(buffer, BUF_SIZE_SOCKET - 1, stdin);
			{
				char *p = NULL;
				p = strstr(buffer, "\n");
				if (p != NULL)
				{
					*p = 0;
				}
				else
				{
					/* fclean */
					buffer[BUF_SIZE_SOCKET -1] = 0;
				}
			}
			write_server(sock, buffer);
		}
		else if(FD_ISSET(sock, &rdfs))
		{
			int n = read_server(sock, buffer);

			/*server down*/
			if (n == 0)
			{
				printf("Server disconnected !\n");
				break;
			}
			puts(buffer);
			write_server(sock, "ok");
		}
	}
	end_connection(sock);
	return (0);
}

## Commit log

2016-04-17 Commencement des schemas Altium pour POC Marvin
    [Bill of Materials-Bill of Materials.xlsx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]
2016-04-18 Ajout des relais, servo et sonar au POC
    [PIC.SchDoc, POC_Marvin.PrjPcb, POC_Marvin.SchLib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]
2016-04-19 Chanagement dans le schemsatics des relais, ajout du IR sensor
    [IrSensor.SchDoc, POC_Marvin.PrjPcb, POC_Marvin.SchLib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]
2016-04-21 Ajout du projet template MPLAB pour le POC
    [IrSensor.SchDoc, PIC.SchDoc, POC_Marvin.PrjPcb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]
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2016-04-22 ajout de la lib PI
    [IrSensor_GP2Y0A02YK0F.PcbLib, POC_Marvin.SchLib]
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2016-04-25 Implementation du AnalogRead, mais probleme de compilation
    [main.c]
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2016-04-28 avancement schemas, leds + quelques branchements
    [Led_mix.SchDoc, Leds_pack.SchDoc, Leds_parra.SchDoc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]
2016-05-02 Ajout de condensateurs de decouplage pour la commande des alims
    [Power_v2.SchDoc]
2016-05-03 Regulation / protection de tension
    [LED_V2.SchDoc, POC_Marvin.PrjPcb, Power_v2.SchDoc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]
2016-05-03 precision sur schemas, pour premier envoi Greg
    [LED_V2.SchDoc, PIC.SchDoc, POC_Marvin.PrjPcb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]
2016-05-06 Tripaille PIC32 + debug
    [LED_V2.SchDoc, PIC.SchDoc, POC_Marvin.PrjPcb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]
2016-05-07 avancement footprint
    [MarvinPcbLib1.PcbLib, POC_Marvin.PrjPcb, Power_v2.SchDoc]
2016-05-07 ajout des footprints de quelques foot prints
    [MarvinPcbLib2.PcbLib]
2016-05-07 avancement footprint 2
    [LED_V2.SchDoc, MarvinPcbLib1.PcbLib, Power_v2.SchDoc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]
2016-05-07 integration lib 2
    [POC_Marvin.PrjPcb]
2016-05-09 Finition des footprints en cours
    [MarvinPcbLib2.PcbLib, POC_Marvin.PrjPcb]
2016-05-09 footprint diode Zener
    [PcbLib1.PcbLib]
2016-05-09 footprints ok
    [MarvinPcbLib2.PcbLib, Power_v2.SchDoc]
2016-05-09 Changemens majeurs, ajout d'un schema global pour design hierarchique
    [IrSensor.SchDoc, LED_V2.SchDoc, LED_V3.SchDoc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]
2016-05-09 Nouveau design du PCB
    [IrSensor.SchDoc, LED_V3.SchDoc, Marvin_PCB.PcbDoc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]
2016-05-10 Mise en conformite en cours
    [IrSensor.SchDoc, Marvin_PCB.PcbDoc, Marvin_global.SchDoc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]
2016-05-11 Creation composant et footprint pour le PIC32MX270F256B
    [MarvinPcbLib2.PcbLib, PIC.SchDoc, POC_Marvin.SchLib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]
2016-05-12 avancement placement sur PIC, footprint RJ11, MAJ jack
    [IrSensor.SchDoc, LED_V3.SchDoc, MarvinPcbLib2.PcbLib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]
2016-05-13 Modif regul
    [Power_v2.SchDoc, Regul.SchDoc]
2016-05-16 WIP PIC
    [PIC.SchDoc]
2016-05-16 Modif des footprints traversants. TODO: debug compil
    [IrSensor.SchDoc, LED_V3.SchDoc, MarvinPcbLib2.PcbLib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]
2016-05-17 PCB suite
    [MarvinPcbLib2.PcbLib, Marvin_PCB_V2.PcbDoc, Power_v2.SchDoc]
2016-05-17 routage Mark 1
    [Marvin_PCB_V2.PcbDoc]
2016-05-18 ajout de la pin 15 Vbus avec un pull down, fin de la version 2 du PCb, debut de la v3 du PCb
    [Marvin_PCB_V2.PcbDoc, Marvin_PCB_v3.PcbDoc, PIC.SchDoc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]
2016-05-18 debut de la v3
    [Marvin_PCB_v3.PcbDoc]
2016-05-19 pause cafe
    [Marvin_PCB_v3.PcbDoc]
2016-05-19 save avant de changer le footprint de J4
    [Marvin_PCB_v3.PcbDoc]
2016-05-19 petite sauvegarde
    [MarvinPcbLib2.PcbLib, Marvin_PCB_v3.PcbDoc]
2016-05-19 Fin routage V3
    [Marvin_PCB_V2.PcbDoc, Marvin_PCB_v3.PcbDoc, POC_Marvin.PrjPcb]
2016-05-20 referencement des compo pour BoM
    [Bill of Materials-POC_Marvin.xlsx, IrSensor.SchDoc, LED_V3.SchDoc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]
2016-05-21 save before polygon poor
    [Bill of Materials-PIC.xlsx, Bill of Materials-POC_Marvin.xlsx, Bill of Materials.xlsx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]
2016-05-21 polygon poor OK, Outputjob lookslike OK
    [Marvin_PCB_v3.PcbDoc]
2016-05-21 footprint Marvin view
    [MarvinPcbLib2.PcbLib, Marvin_PCB_v3.PcbDoc, Regul.SchDoc]
2016-05-24 modification de c9, validation des outputs jobs, todo: modif footprints condos + design rules checks
    [Bill of Materials.xlsx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]
2016-05-24 MaJ footprint condo, masse pourtour
    [MarvinPcbLib2.PcbLib, Marvin_PCB_v3.PcbDoc, POC_Marvin.PrjPcb]
2016-05-25 Fin du PCB, astlabista baby
    [MarvinPcbLib2.PcbLib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]
2016-05-25 Marquage + logo
    [MarvinPcbLib2.PcbLib, Marvin_PCB_v3.PcbDoc]
2016-05-26 Ajout des refs des condos electrolytiques. Ajout du fournisseur a la BOM. Ajout de quelques modeles pour vue 3D. Go pour prod
    [Bill of Materials.xlsx, MarvinPcbLib2.PcbLib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]
2016-05-27 debut du soft proto du projet, fonction calcul mediane et tri insertion OK, debut des fonctions des sonars
2016-05-27 modification de la fonction mediane pour prendre en compte les zeros, ajout de la fonction qui capture les donnnes avec un micro
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2016-06-01 fin de la v01 de la fonction timer , debut des fonctions servos
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2016-06-03 modification de la fnction timer , pour avoir une fonctionde calucl des prescalleurs" debut de la fonction de luart
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2016-06-04 fonction sonar OK, reste a finir de tester avec plusieurs sonar
    [Marvin_PCB_v3.PcbDoc, POC_Marvin.PrjPcb]
2016-06-06 Correction de references compo schemas / BOM
    [Bill of Materials.xls, Bill of Materials.xlsx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]
2016-06-07 BOM Final
    [Bill of Materials.xls, Bill of Materials.xlsx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]
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2016-06-23 Transition new PIC: Code Timer OK, code servo OK, test de certaine PIN a HIGH
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2016-06-25 Conversion de la donne de l'ir en mV, debut du calcul en cm
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2016-06-27 Premier fonctionnement complet, gribouillit de code
    [blablablabla.xlsx]
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2016-07-08 correction move to position, debut comportement sur le temps
    [main.c, marvin.c, servo.c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]
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
